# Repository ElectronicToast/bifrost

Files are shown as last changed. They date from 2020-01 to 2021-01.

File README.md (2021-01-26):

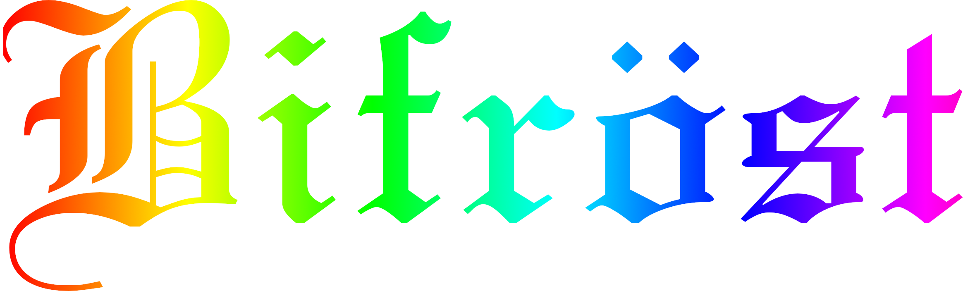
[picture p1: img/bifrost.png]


  

Arduino Nano RGB LED controller

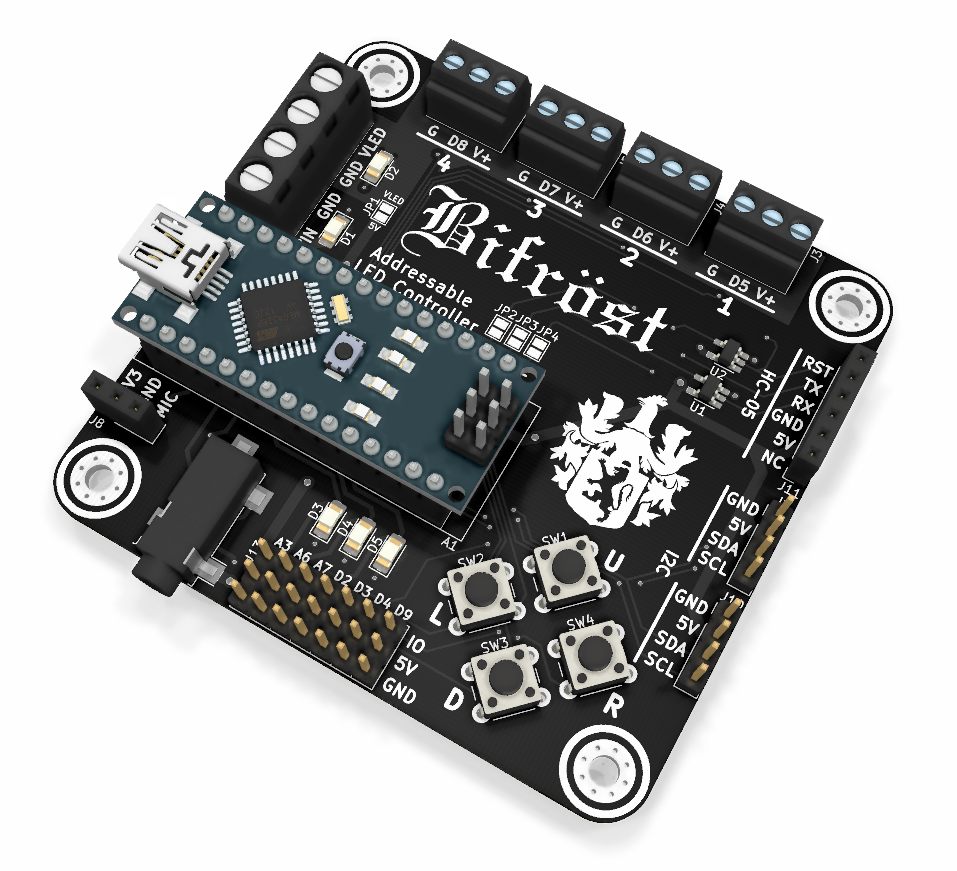
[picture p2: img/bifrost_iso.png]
iso


## Description

Bifrost is an expansion board for the Arduino Nano v3.x for control of WS2811-based addressable RGB LED strips. Four LED outputs are provided for driving multiple strips; however, the RAM limitations of the ATmega328p must be kept in mind. A stereo audio jack and a socket for an [Adafruit MAX4466 electret microphone](https://www.adafruit.com/product/1063) are present for music visualization applications.

Four pushbuttons and three status LEDs onboard permit physical user control. If different peripherals are desired, an auxiliary connection header is provided for adding off-board I/O.

A socket for an HC-05 module is present, permitting serial communication and programming over Bluetooth. I2C connectors are provided for chaining multiple boards. A microSD card socket is also provided for storage of configuration settings, animations, etc.

This project is designed with KiCad EDA v.5.1.5. Documentation can be found under `/doc` and fabrication files under `/gerber`.

## Photos

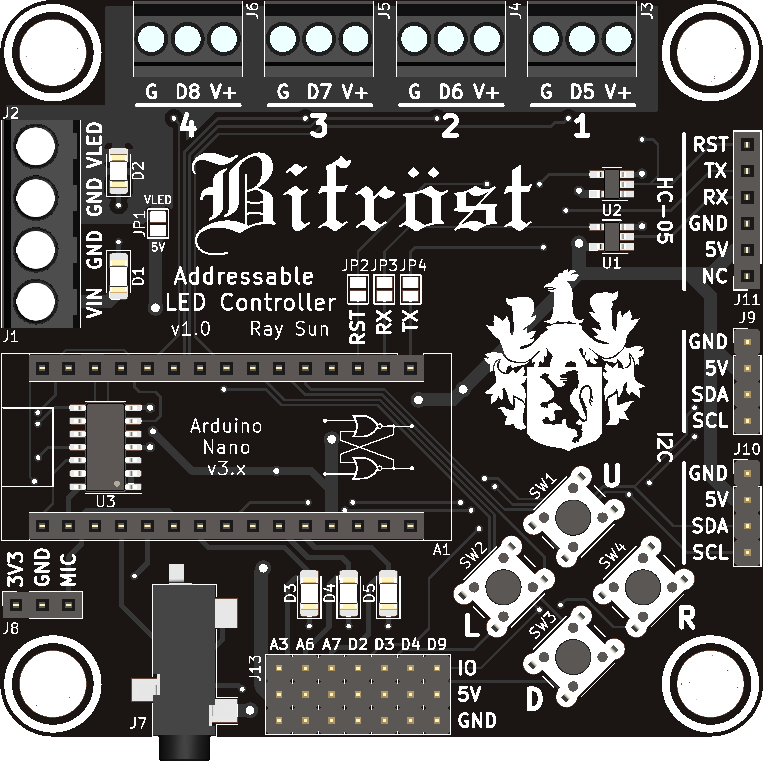
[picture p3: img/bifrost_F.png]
front


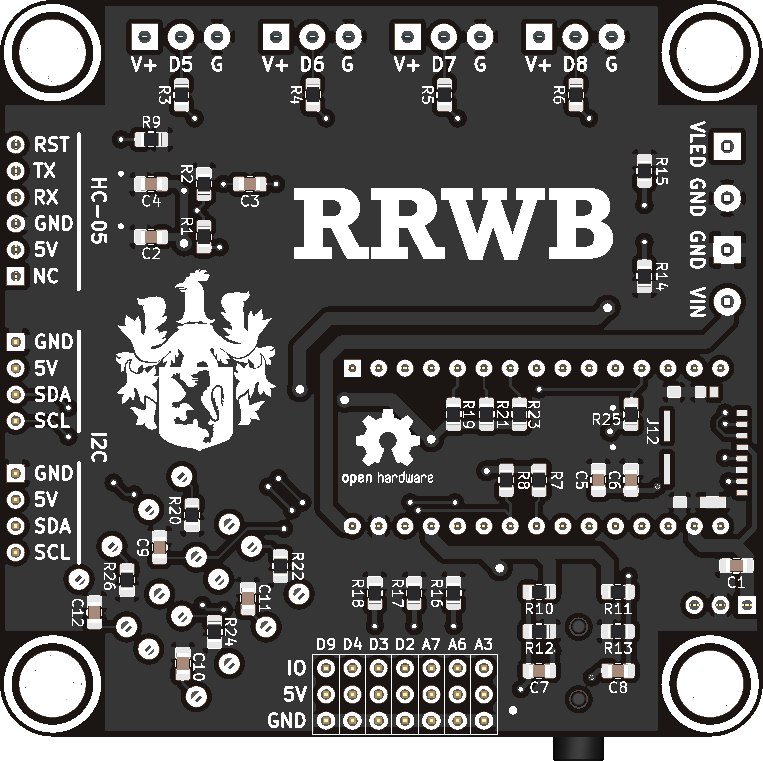
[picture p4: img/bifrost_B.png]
back


## Usage
Connect DC power (7-12V recommended) to the VIN port. If LED output power is desired, connect external LED power to the VLED port. Do not attempt to draw more than 1-2A of current from any one LED output.

To power the board from the VLED input, bridge jumper JP1. 5V must be provided to VLED if JP1 is closed.

To use an HC-05 module for Bluetooth serial, bridge jumpers JP3 and JP4. Do not connect additional UART devices to the Arduino Nano hardware UART if the HC-05 is used. A 100 ohm resistor on JP3 is recommended to prevent TX bus contention. To enable Bluetooth programming, also bridge JP2.

## Author
- Ray Sun - Undergraduate, Electrical Engineering, Caltech, Class of 2020

## Licensing
This project is released under the terms of the MIT License.

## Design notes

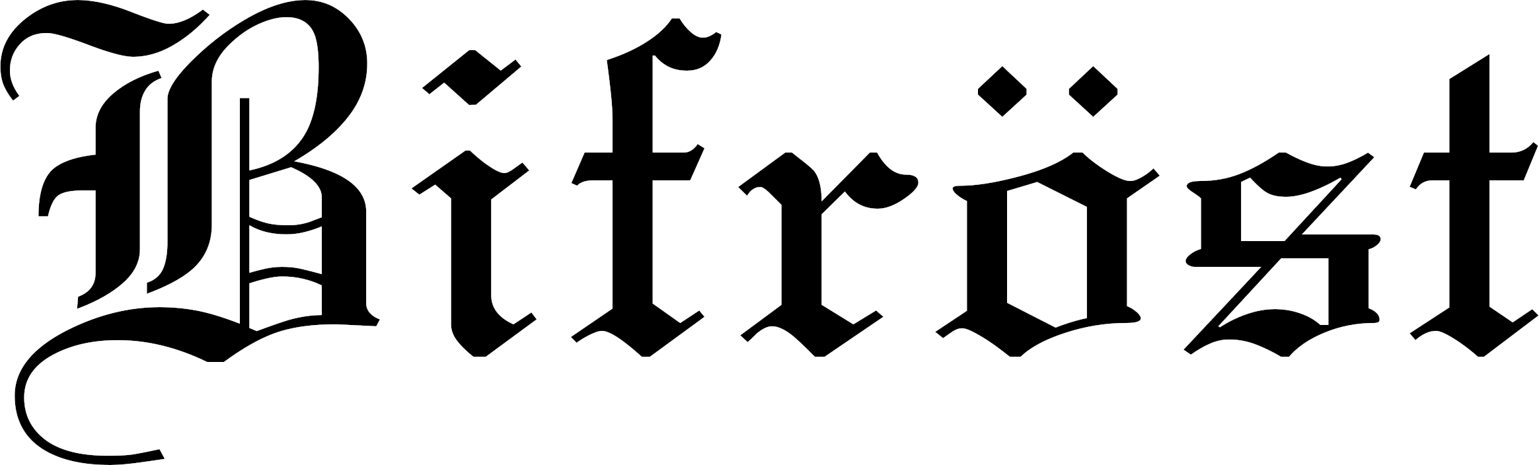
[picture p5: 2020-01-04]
img/bifrost-bw.png

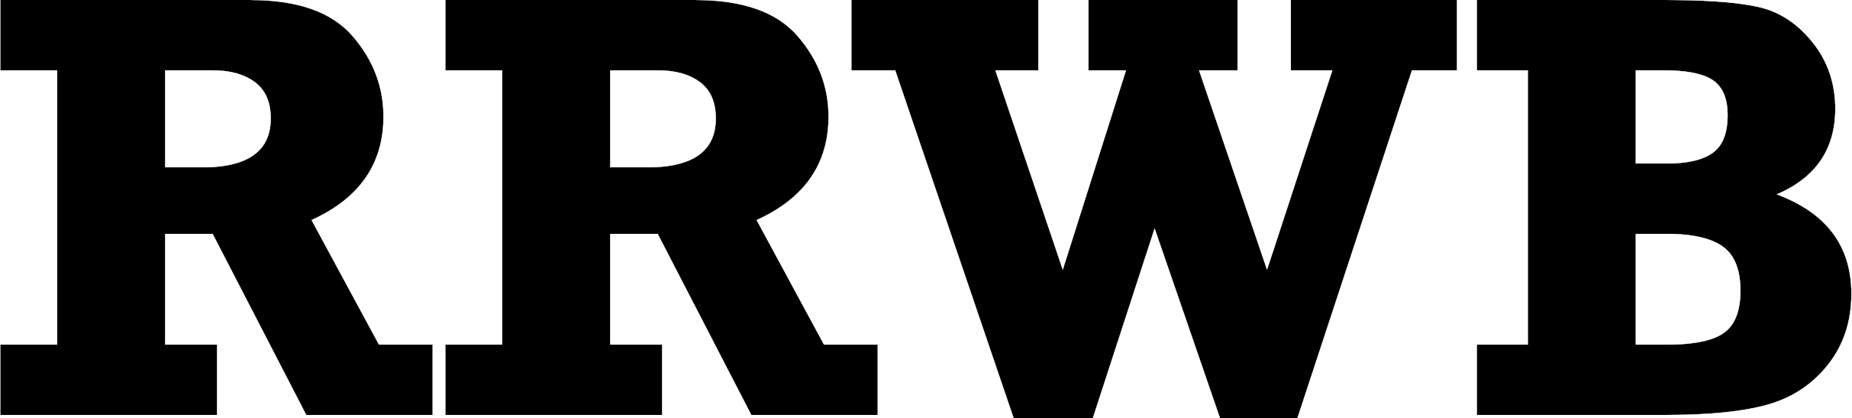
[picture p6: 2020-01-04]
img/rrwb.png

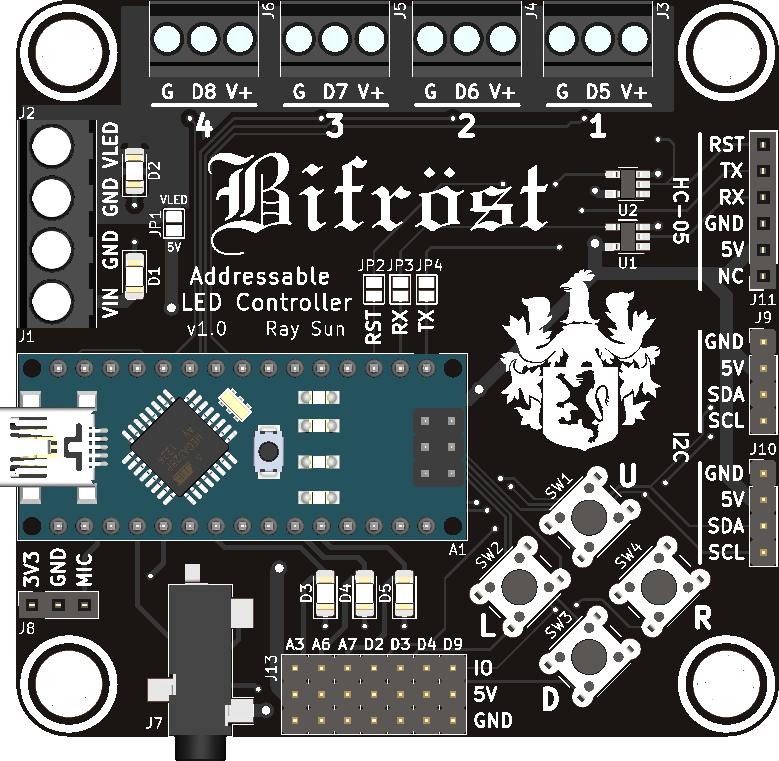
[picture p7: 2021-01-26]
img/bifrost_F_with_nano.png

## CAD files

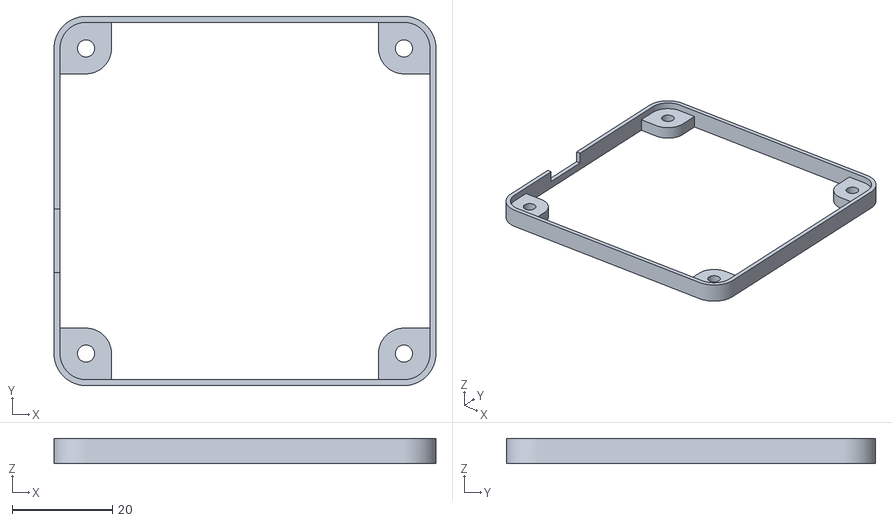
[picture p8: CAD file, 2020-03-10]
bumper/bifrost-bumper.stl
76.3 x 73.8 x 5.08

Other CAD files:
bumper/bifrost-bumper.ipt

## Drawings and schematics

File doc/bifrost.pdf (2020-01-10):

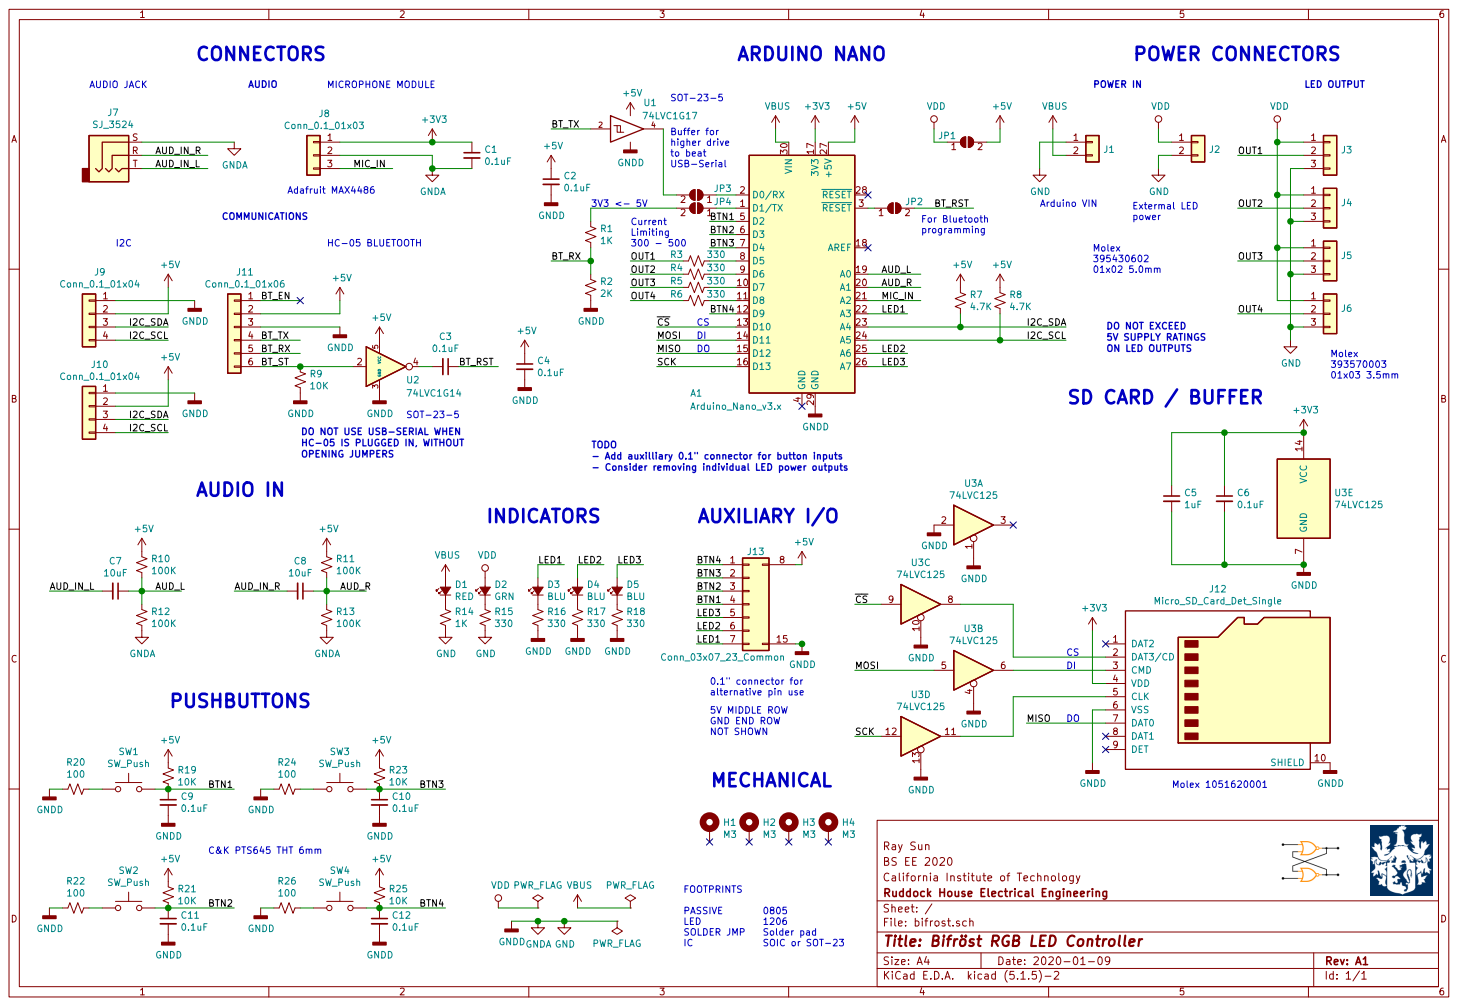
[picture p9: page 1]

DI DO ARDUINO NANO

SOT-23-5 Buffer for higher drive
74LVC1G17

Extermal LED power 3V3 <- 5V C&K PTS645 THT 6mm

HC-05 IS PLUGGED IN, WITHOUT OPENING JUMPERS HC-05 BLUETOOTH AUDIO IN

DO NOT EXCEED
5V SUPPLY RATINGS ON LED OUTPUTS

1K GNDD
- Consider removing individual LED power outputs DO NOT USE USB-SERIAL WHEN

TODO
- Add auxilliary 0.1" connector for button inputs

0.1" connector for alternative pin use

California Institute of Technology BS EE 2020 Ray Sun

Id: 1/1 Title: Bifröst RGB LED Controller File: bifrost.sch Sheet: / Ruddock House Electrical Engineering

1206 Solder pad SOIC or SOT-23

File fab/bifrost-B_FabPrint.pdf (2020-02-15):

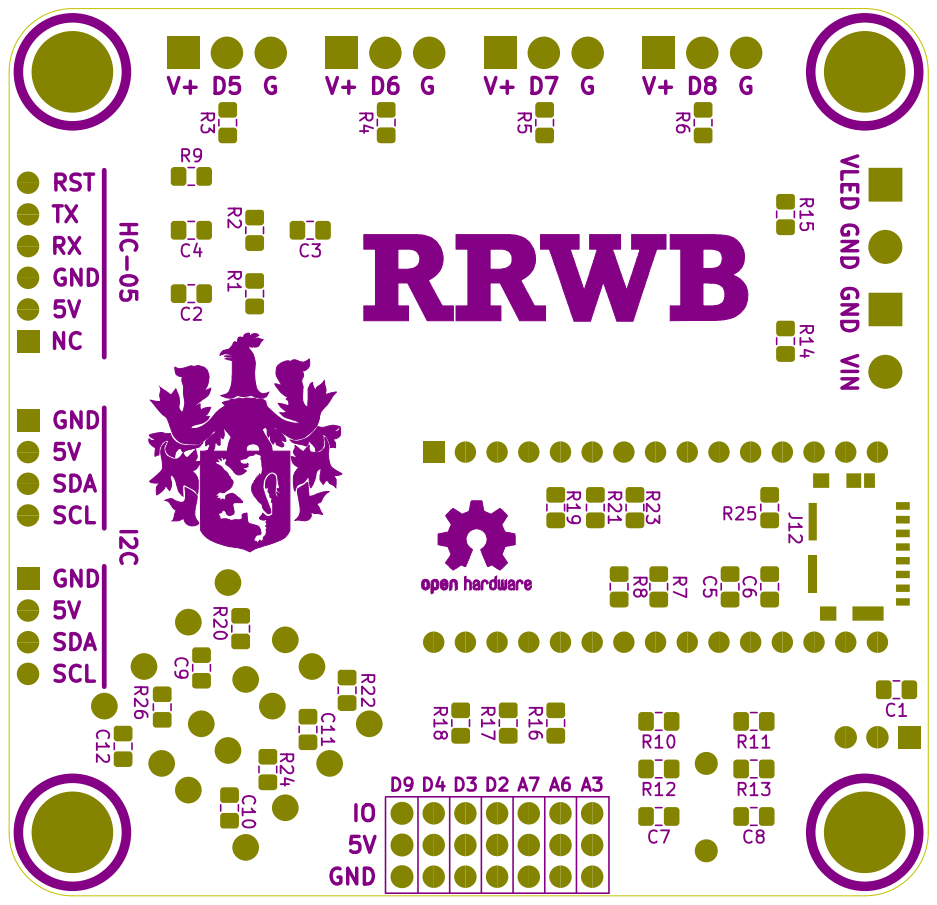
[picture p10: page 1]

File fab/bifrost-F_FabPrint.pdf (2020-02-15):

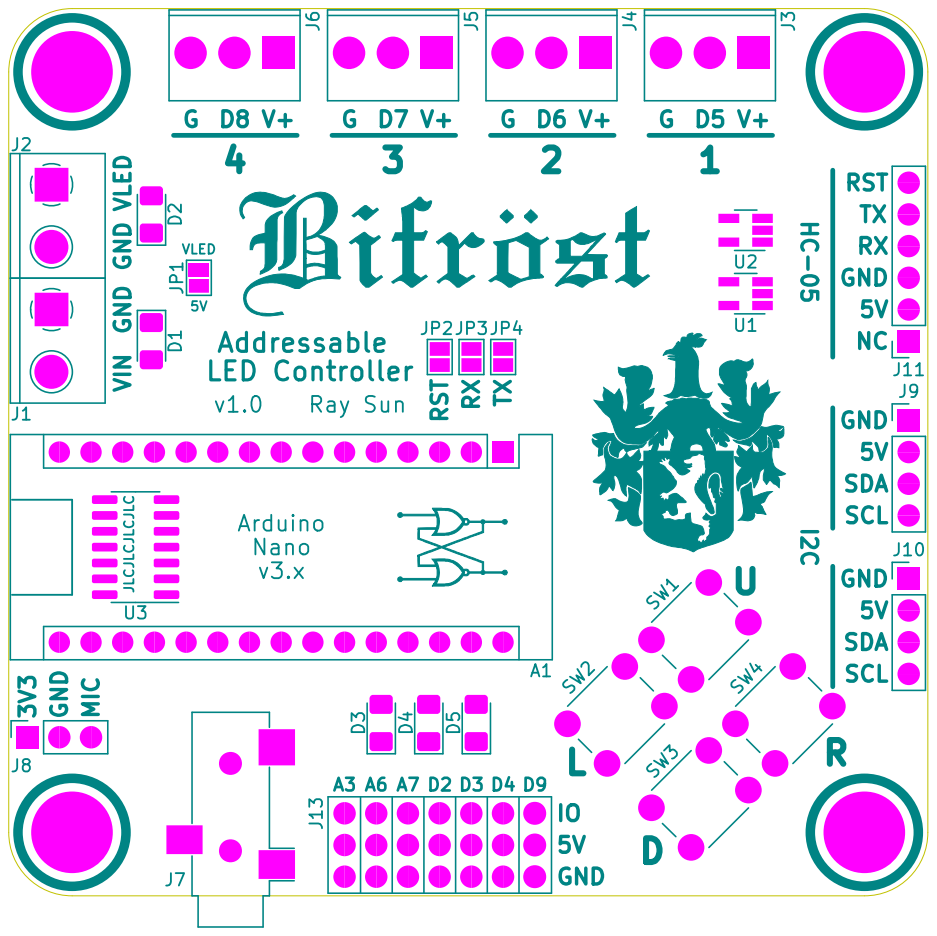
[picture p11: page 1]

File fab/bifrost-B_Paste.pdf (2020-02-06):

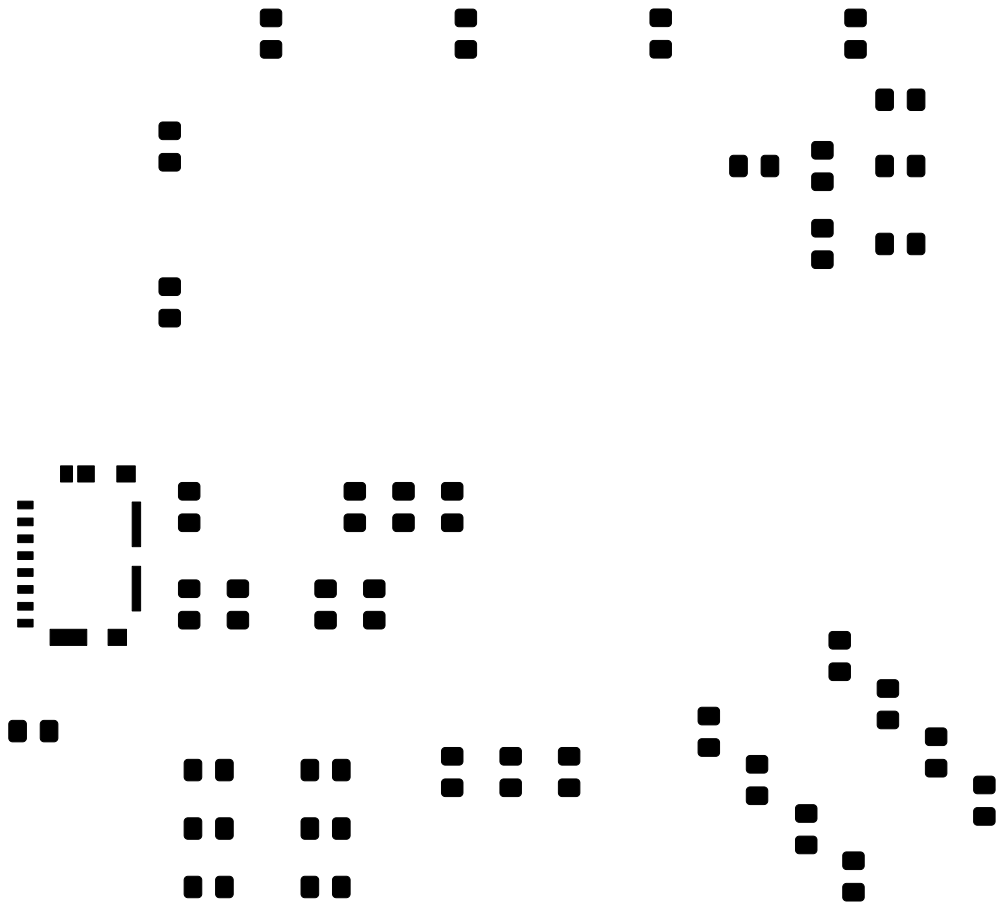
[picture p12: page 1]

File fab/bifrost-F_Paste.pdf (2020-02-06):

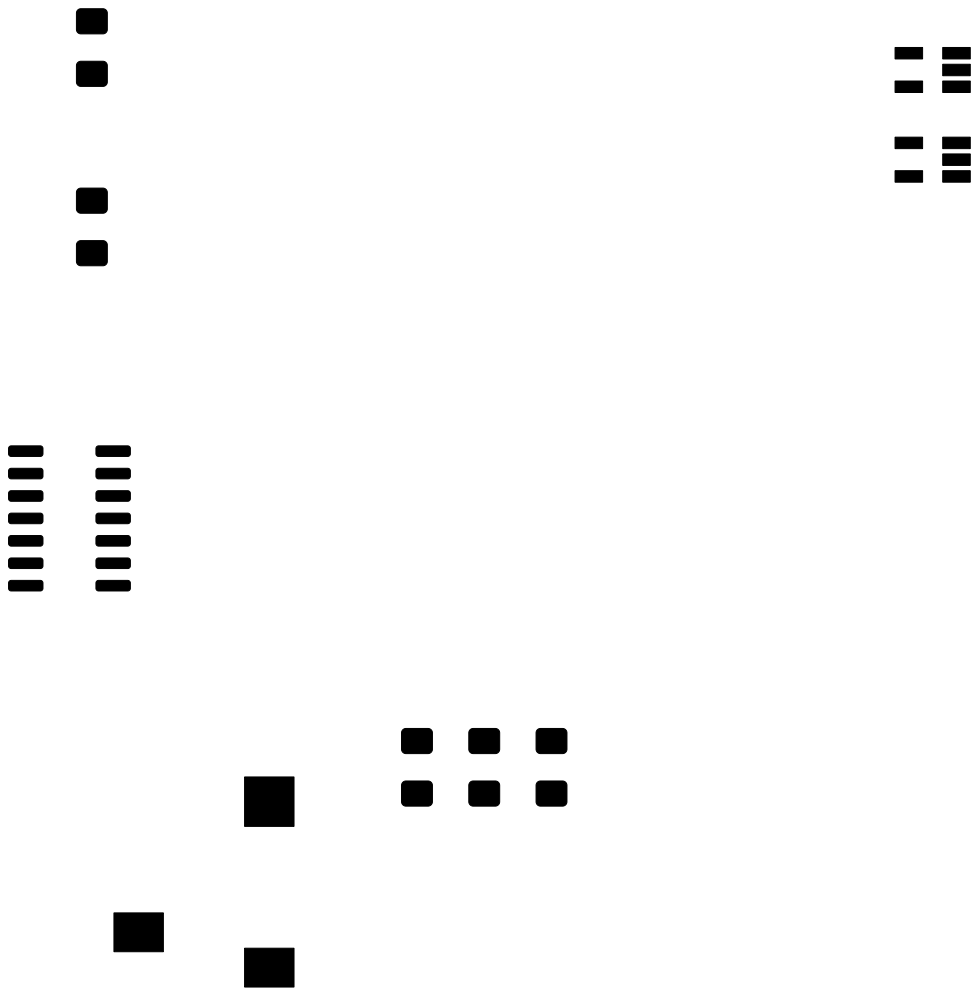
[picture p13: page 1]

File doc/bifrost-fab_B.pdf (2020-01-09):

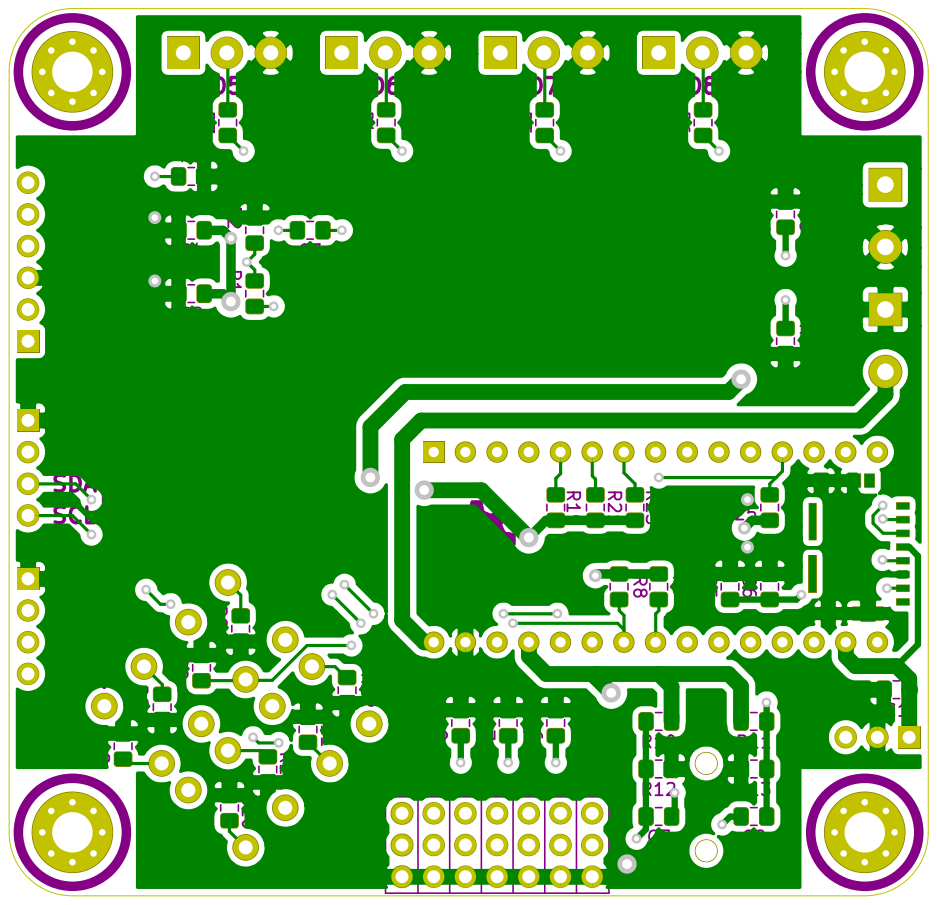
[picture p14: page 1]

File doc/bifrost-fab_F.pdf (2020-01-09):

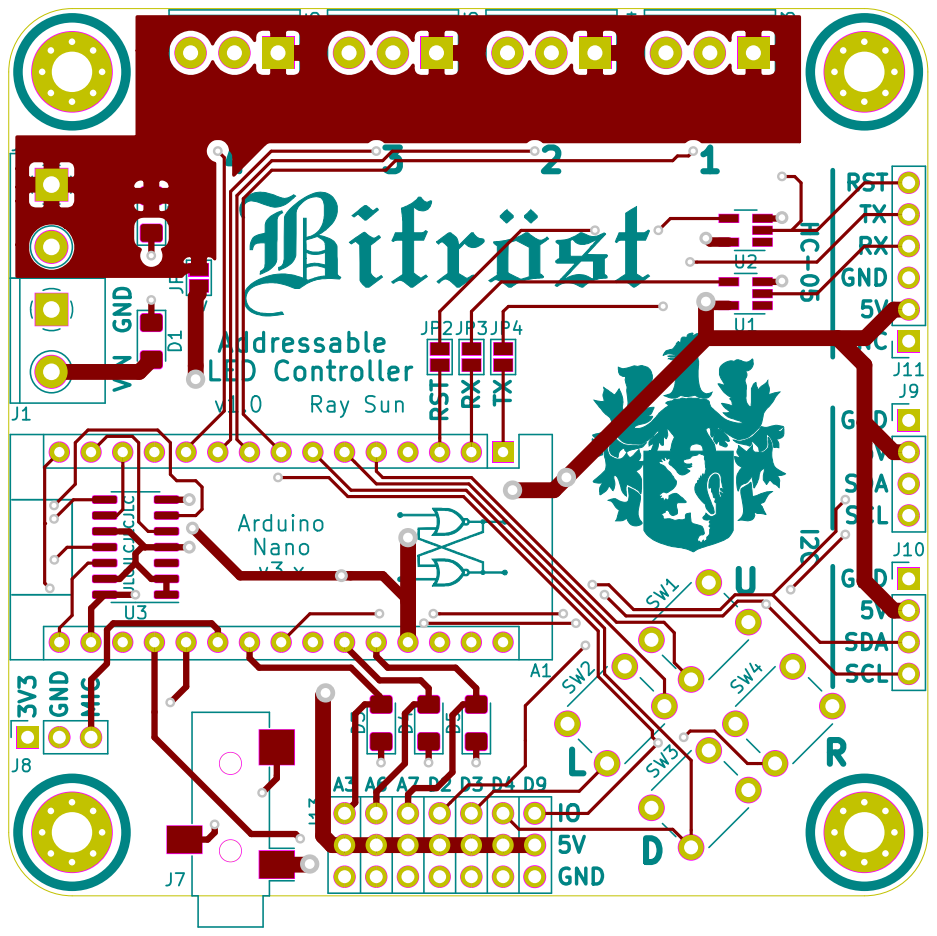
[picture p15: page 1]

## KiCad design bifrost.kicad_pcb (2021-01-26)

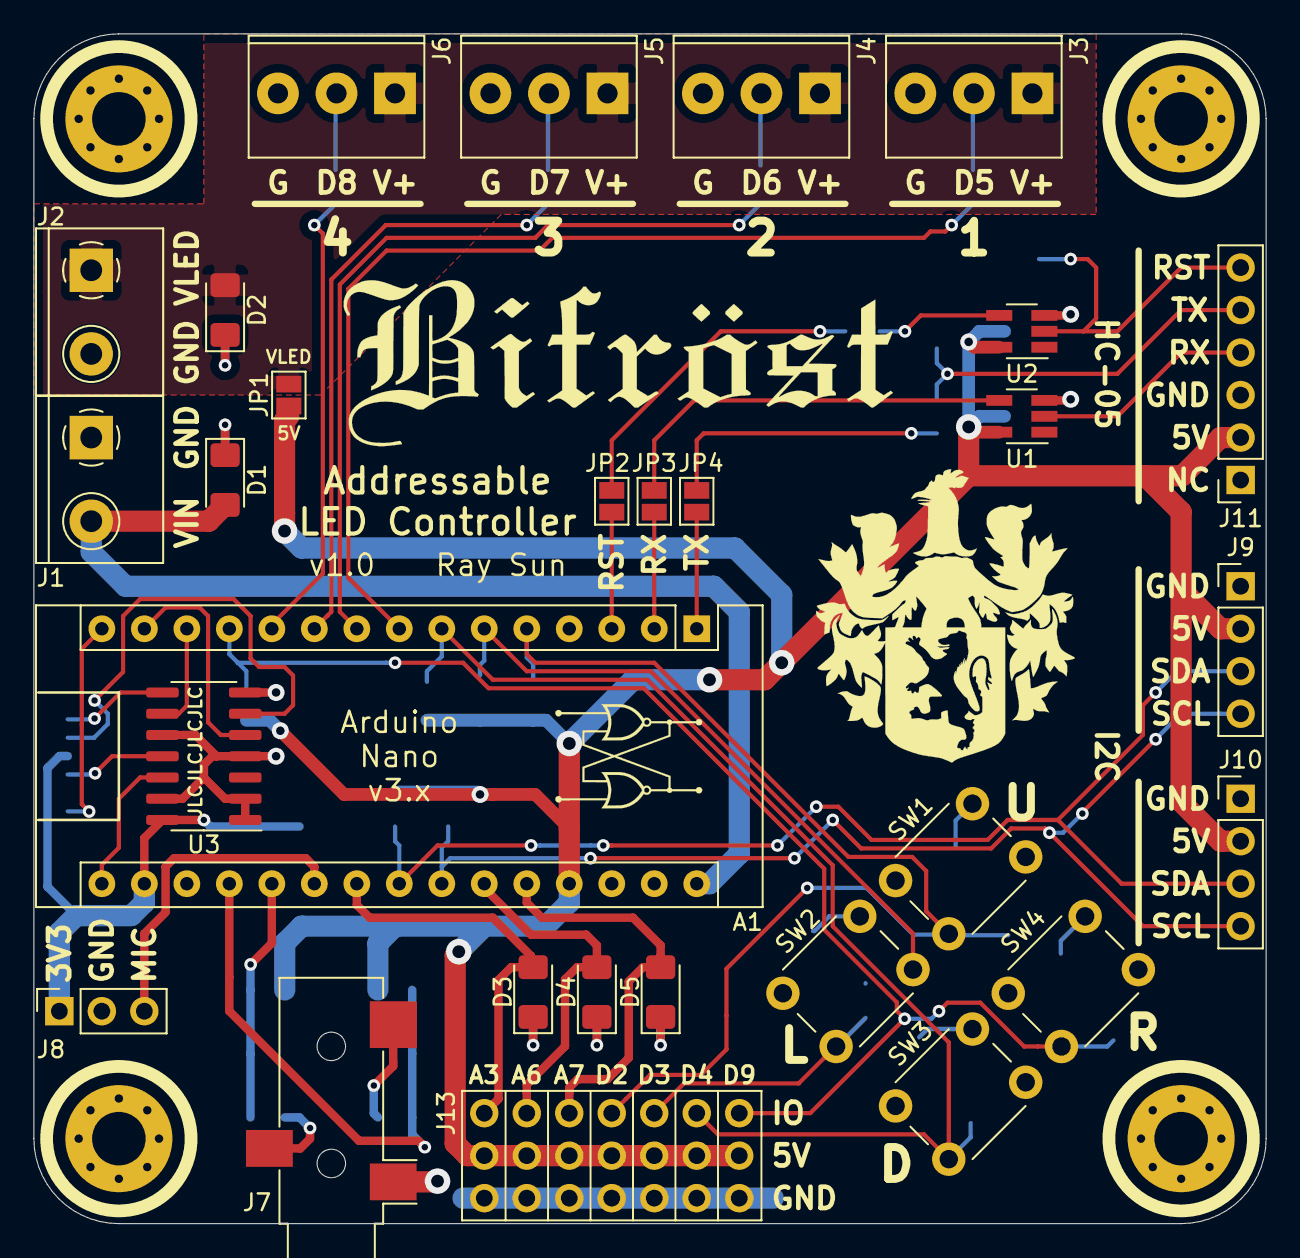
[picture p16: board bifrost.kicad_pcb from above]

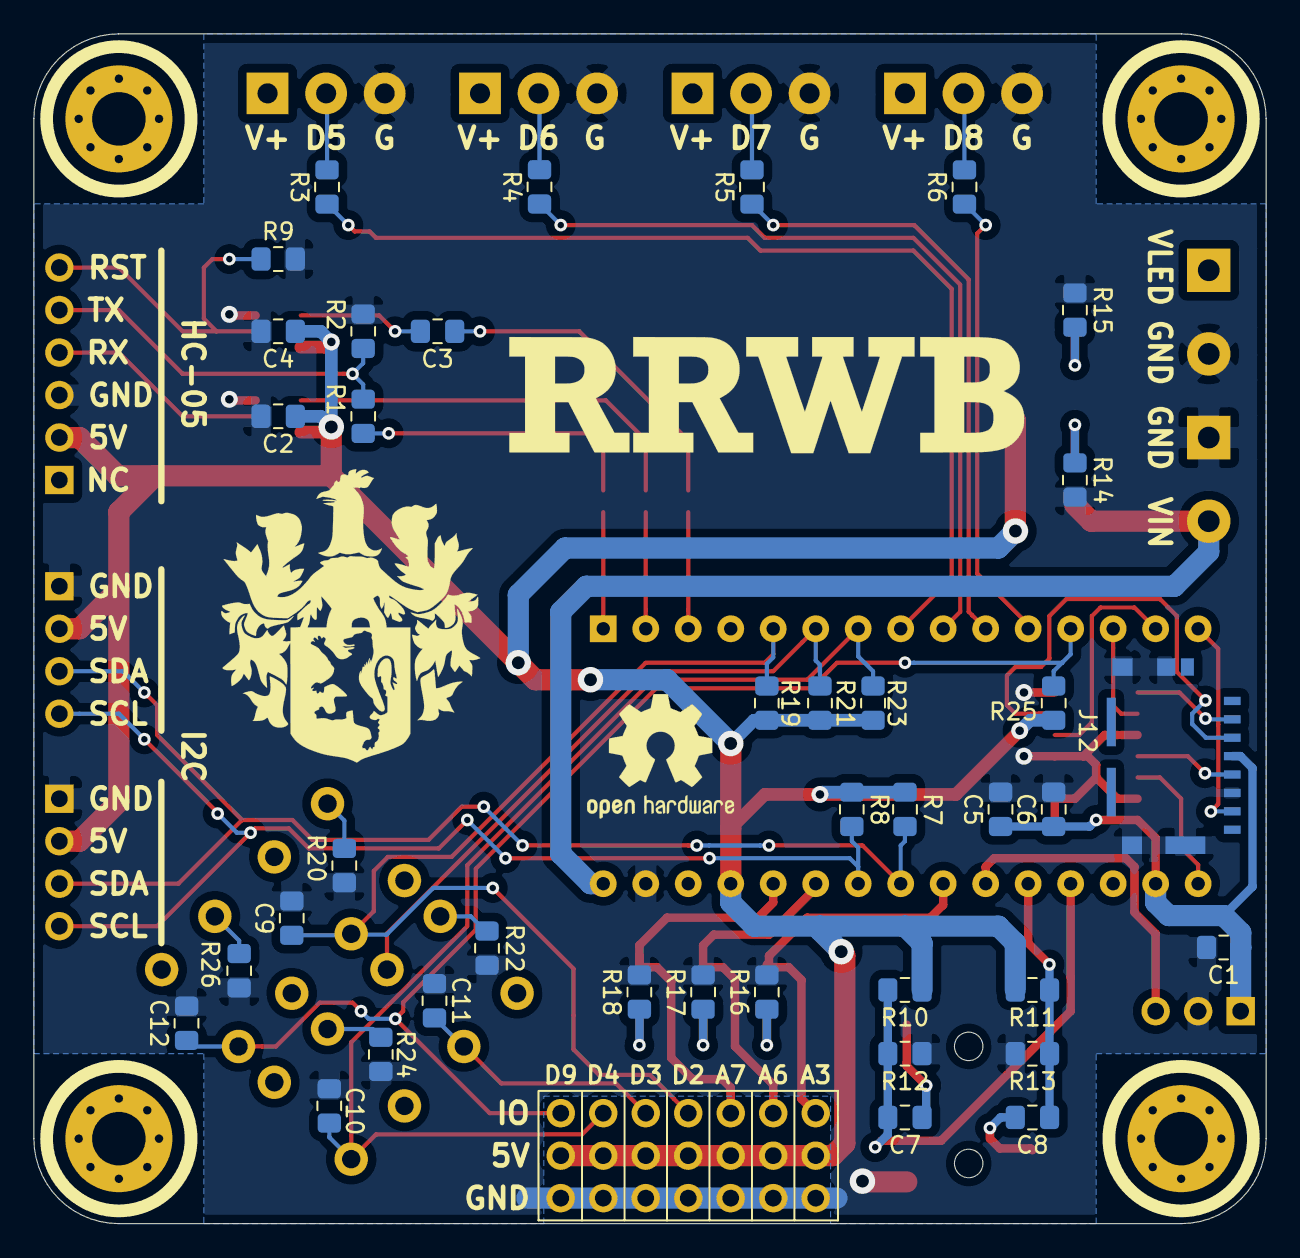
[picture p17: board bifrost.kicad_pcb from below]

Board: 2 copper layers, 73.7 x 71.1 mm, 72 parts (39 on the bottom side), 53 nets.

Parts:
A1: Arduino_Nano_v3.x; Arduino_Nano
C1, C2, C3, C4, C6, C9, C10, C11, C12: 0.1uF; C_0805_2012Metric_Pad1.15x1.40mm_HandSolder
C5: 1uF; C_0805_2012Metric_Pad1.15x1.40mm_HandSolder
C7, C8: 10uF; C_0805_2012Metric_Pad1.15x1.40mm_HandSolder
D1: RED; LED_1206_3216Metric_Pad1.42x1.75mm_HandSolder
D2: GRN; LED_1206_3216Metric_Pad1.42x1.75mm_HandSolder
D3, D4, D5: BLU; LED_1206_3216Metric_Pad1.42x1.75mm_HandSolder
H1, H2, H3, H4: M3; MountingHole_3.2mm_M3_Pad_Via
J1, J2: 395430002; TerminalBlock_Molex_395430602_1x02_P5.00mm_Horizontal
J3, J4, J5, J6: 393570003; TerminalBlock_Molex_393570003_1x03_P3.50mm_Horizontal
J7: SJ_3524; Jack_3.5mm_CUI_SJ-3523-SMT_Horizontal
J8: Conn_0.1_01x03; PinSocket_1x03_P2.54mm_Vertical
J9, J10: Conn_0.1_01x04; PinHeader_1x04_P2.54mm_Vertical
J11: Conn_0.1_01x06; PinSocket_1x06_P2.54mm_Vertical
J12: Micro_SD_Card_Det_Single; microSD_Molex_1051620001
J13: Conn_03x07_23_Common; PinHeader_03x07_P2.54mm_Vertical
JP1, JP2, JP3, JP4: SolderJumper_2_Open; SolderJumper-2_P1.3mm_Open_Pad1.0x1.5mm
R1, R14: 1K; R_0805_2012Metric_Pad1.15x1.40mm_HandSolder
R2: 2K; R_0805_2012Metric_Pad1.15x1.40mm_HandSolder
R3, R4, R5, R6, R15, R16, R17, R18: 330; R_0805_2012Metric_Pad1.15x1.40mm_HandSolder
R7, R8: 4.7K; R_0805_2012Metric_Pad1.15x1.40mm_HandSolder
R9, R19, R21, R23, R25: 10K; R_0805_2012Metric_Pad1.15x1.40mm_HandSolder
R10, R11, R12, R13: 100K; R_0805_2012Metric_Pad1.15x1.40mm_HandSolder
R20, R22, R24, R26: 100; R_0805_2012Metric_Pad1.15x1.40mm_HandSolder
SW1, SW2, SW3, SW4: SW_Push; SW_PUSH_6mm_H5mm
U1: 74LVC1G17; SOT-23-5_HandSoldering
U2: 74LVC1G14; SOT-23-5_HandSoldering
U3: 74AHCT125; SOIC-14_3.9x8.7mm_P1.27mm

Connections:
+3V3: A1.17, C1.1, C5.1, C6.1, J8.1, J12.4, U3.14
+5V: A1.27, C2.1, C4.1, J9.2, J10.2, J11.2, J13.8, J13.9, J13.10, J13.11, J13.12, J13.13, J13.14, JP1.2, R7.1, R8.1, R10.1, R11.1, R19.1, R21.1, R23.1, R25.1, U1.5, U2.5
/AUD_IN_L: C7.2, J7.T
/AUD_IN_R: C8.2, J7.R
/AUD_L: A1.19, C7.1, R10.2, R12.1
/AUD_R: A1.20, C8.1, R11.2, R13.1
/BTN1: A1.5, C9.1, J13.4, R19.2, SW1.2
/BTN2: A1.6, C11.1, J13.3, R21.2, SW2.2
/BTN3: A1.7, C10.1, J13.2, R23.2, SW3.2
/BTN4: A1.12, C12.1, J13.1, R25.2, SW4.2
/BT_RST: C3.1, JP2.2
/BT_RX: J11.5, R1.2, R2.1
/BT_ST: J11.6, R9.1, U2.2
/BT_TX: J11.4, U1.2
/I2C_SCL: A1.24, J9.4, J10.4, R8.2
/I2C_SDA: A1.23, J9.3, J10.3, R7.2
/LED1: A1.22, D3.2, J13.7
/LED2: A1.25, D4.2, J13.6
/LED3: A1.26, D5.2, J13.5
/MIC_IN: A1.21, J8.3
/MISO: A1.15, J12.7
/MOSI: A1.14, U3.5
/OUT1: J3.2, R3.2
/OUT2: J4.2, R4.2
/OUT3: J5.2, R5.2
/OUT4: J6.2, R6.2
/SCK: A1.16, U3.12
/~CS: A1.13, U3.9
GND: A1.29, C1.2, C2.2, C4.2, C5.2, C6.2, C9.2, C10.2, C11.2, C12.2, J1.1, J2.2, J3.3, J4.3, J5.3, J6.3, J7.S, J8.2, J9.1, J10.1, J11.3, J12.6, J12.10, J13.15, J13.16, J13.17, J13.18, J13.19, J13.20, J13.21, R2.2, R9.2, R12.2, R13.2, R14.2, R15.2, R16.2, R17.2, R18.2, R20.2, R22.2, R24.2, R26.2, U1.3, U2.3, U3.1, U3.2, U3.4, U3.7, U3.10, U3.13
unnamed: A1.1, JP4.1
unnamed: A1.2, JP3.1
unnamed: A1.3, JP2.1
unnamed: A1.8, R3.1
unnamed: A1.9, R4.1
unnamed: A1.10, R5.1
unnamed: A1.11, R6.1
unnamed: C3.2, U2.4
unnamed: D1.1, R14.1
unnamed: D2.1, R15.1
unnamed: D3.1, R16.1
unnamed: D4.1, R17.1
unnamed: D5.1, R18.1
unnamed: J12.2, U3.8
unnamed: J12.3, U3.6
unnamed: J12.5, U3.11
unnamed: JP3.2, U1.4
unnamed: JP4.2, R1.1
unnamed: R20.1, SW1.1
unnamed: R22.1, SW2.1
unnamed: R24.1, SW3.1
unnamed: R26.1, SW4.1
VBUS: A1.30, D1.2, J1.2
VDD: D2.2, J2.1, J3.1, J4.1, J5.1, J6.1, JP1.1

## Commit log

2019-12-17 Create project
    [bifrost.kicad_pcb, bifrost.sch]
2019-12-18 Make schematic
    [bifrost.sch]
2019-12-18 Split LED power bus in half, for more current capability
    [bifrost.sch]
2019-12-18 Fix HC-05 interface
    [bifrost.sch]
2019-12-18 Correct ground domain connection to MCU power input
    [bifrost.sch]
2019-12-20 Select buttons and terminal blocks
    [bifrost.sch]
2019-12-20 Make terminal block footprints
2019-12-20 Add in terminal block footprints and some additional comments
    [bifrost.sch]
2019-12-20 Select output capacitors (might not be necessary)
    [bifrost.sch]
2019-12-20 Fix indicators
    [bifrost.sch]
2019-12-20 Add more comments
    [bifrost.sch]
2019-12-21 Add termination resistors to outputs
    [bifrost.sch]
2019-12-21 Add second I2C connector for easier connection of multiple boards
    [bifrost.sch]
2019-12-23 Move project files to main directory
    [bifrost.kicad_pcb, bifrost.sch]
2019-12-23 Footprint for HC-05 and I2C connectors need update
    [bifrost.sch]
2019-12-23 Add cap to couple Bluetooth reset signal
    [bifrost.sch]
2019-12-23 Begin PCB layout
    [bifrost.kicad_pcb]
2019-12-25 Free up SPI pins for possible SD card
    [bifrost.sch]
2019-12-27 Remove LED power inputs and simplify schematic
    [bifrost.sch]
2019-12-27 Add microSD socket and footprint
2019-12-27 Add microSD socket and buffer IC
    [bifrost.sch]
2019-12-27 Add a buffer to HC-05 TX line to win contention with CH340 on Nano
    [bifrost.sch]
2019-12-27 Replace reset MOSFET with inverter IC
    [bifrost.sch]
2019-12-27 Revise comments
    [bifrost.sch]
2019-12-27 Move things around
    [bifrost.sch]
2019-12-27 Select terminal blocks (need footprints)
    [bifrost.sch]
2019-12-27 Replace solder jumpers with THT jumpers for easier swap between wireless and USB serial
    [bifrost.sch]
2019-12-27 Fix disconnected nets
    [bifrost.sch]
2019-12-28 Add jumper to disconnect 5V power input from Nano
    [bifrost.sch]
2019-12-28 Add redundant pulldown to HC-05 reset
    [bifrost.sch]
2019-12-28 Flip status LED and resistor order for easier layout
    [bifrost.sch]
2019-12-28 Update 2 and 3 pin Molex 3954306xx 5mm pitch footprints
2019-12-28 Make Molex 3935700xx 3.5mm pitch footprints
2019-12-28 Assign remaining footprints
    [bifrost.sch]
2019-12-28 Change status LED resistor values to cut down on different resistance values
    [bifrost.sch]
2019-12-28 Add a separate VIN indicator
    [bifrost.sch]
2019-12-29 Begin placement
    [bifrost.kicad_pcb]
2020-01-04 Fix J11 footprint assignment and switch VIN pinout
    [bifrost.sch]
2020-01-04 Do most placement
    [bifrost.kicad_pcb]
2020-01-04 Move some footprints and designators around
    [bifrost.kicad_pcb]
2020-01-04 Fully split power domains
    [bifrost.sch]
2020-01-04 Start labelling conector pins
    [bifrost.kicad_pcb]
2020-01-04 Continue labelling and start routing
    [bifrost.kicad_pcb]
2020-01-04 Change 5V indicator to external LED power indicator
    [bifrost.sch]
2020-01-04 Remap 74AHCT125 buffer for easier routing
    [bifrost.sch]
2020-01-04 Continue routing
    [bifrost.kicad_pcb]
2020-01-04 Renumber switches
    [bifrost.sch]
2020-01-04 Switch pin jumpers to solder jumpers to reduce part count
    [bifrost.sch]
2020-01-04 Add project logos and footprints
2020-01-04 Finish most routing
    [bifrost.kicad_pcb]
2020-01-04 Move logos around
    [bifrost.kicad_pcb]
2020-01-04 Clean up
    [bifrost.kicad_pcb]
2020-01-04 Move refdes around
    [bifrost.kicad_pcb]
2020-01-04 Make 03x07 pin header symbol and footprint for auxiliary I/O connector
    [bifrost.kicad_pcb, bifrost.sch]
2020-01-04 Change label
    [bifrost.sch]
2020-01-04 Place aux I/O connector on PCB
    [bifrost.kicad_pcb, bifrost.sch]
2020-01-05 Complete routing
    [bifrost.kicad_pcb]
2020-01-05 Snap some traces to pads
    [bifrost.kicad_pcb]
2020-01-05 Edit footprint silk and add pin labels
    [bifrost.kicad_pcb]
2020-01-09 Check for fabrication
    [bifrost.kicad_pcb]
2020-01-09 Generate Gerbers for production
    [bifrost-B_Cu.gbr, bifrost-B_Mask.gbr, bifrost-B_SilkS.gbr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]
2020-01-09 Generate schematic and fabrication prints
2020-01-09 Add board renders
2020-01-10 Replace 74AHCT125 with 3V3-compatible equivalent 74LVC125
    [bifrost.sch]
2020-02-15 Add 2x scale fabrication prints
2020-02-24 Add dimensions
    [bifrost.kicad_pcb]
2020-02-24 Add bumper 3D print to protect exposed underside pins
    [bifrost-bumper.ipt, bifrost-bumper.stl]
2020-03-10 Make bumper thicker for sturdier 3D printing (3 x 0.4mm)
    [bifrost-bumper.ipt, bifrost-bumper.stl]
2021-01-26 Add 3d model references
    [bifrost.kicad_pcb]
2021-01-26 Fix image filename case
